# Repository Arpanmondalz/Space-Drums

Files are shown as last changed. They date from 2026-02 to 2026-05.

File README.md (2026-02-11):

# Space Drums

Space Drums is an open source computer vision-based air drumming system. It utilizes a smartphone as a wireless camera to track hand positions via MediaPipe and ESP32-based drumsticks to trigger hits via UDP.

This project enables a virtual drum kit experience in mid-air with real-time audio feedback.

---

## Project Structure

The repository is organized into three primary components:

*   **linux-server/**: The optimized Python server for Linux systems. Recommended for lowest latency.
*   **windows-server/**: The standard Python server for Windows 10 and 11.
*   **firmware/**: C++ firmware for the ESP32-based drumsticks.

---

## Hardware Requirements

*   **Computer**: A laptop or desktop running Linux (Ubuntu/Mint) or Windows 10/11.
*   **Smartphone**: Any modern smartphone with a camera and web browser (used as the video source).
*   **Space Drum sticks**
*   **Network**: Both the computer and smartphone must be connected to the same WiFi network.

---

## Version Comparison

### Linux Version (Recommended)
Optimized for high performance. It utilizes direct kernel access for video (V4L2) and audio (ALSA), achieving sub-10ms audio response and superior frame rate stability. It supports high-priority process scheduling.

### Windows Version
Easier to set up using standard Windows drivers (DirectShow). While latency is slightly higher due to the Windows audio stack, it is fully functional for standard use.

---

## Installation and Setup

### 1. ESP32 Firmware
Flash the code located in the `firmware/` folder to your ESP32 boards.

1.  Open the project in the Arduino IDE or PlatformIO.
2.  Update the WiFi credentials (`SSID` and `PASSWORD`) in the source code.
3.  Flash one stick configured as **LEFT** and the other as **RIGHT** (refer to the definitions at the top of the firmware file).

### 2. Python Server Setup
Ensure Python 3.10 or newer is installed.

#### Linux Setup
Navigate to the `linux-server/` directory and run:
```bash
sudo apt-get install libgl1 libasound2-dev
python3 -m venv venv
source venv/bin/activate
pip install -r requirements.txt
```
*Note: Granting high-priority permissions to the Python executable is recommended for optimal performance.*

#### Windows Setup
Navigate to the `windows-server/` directory in PowerShell:
```powershell
python -m venv venv
.\venv\Scripts\Activate
pip install -r requirements.txt
```

### 3. Audio Files

All audio files can be downloaded from the sounds/ folder

---

## Running the System

1.  **Start the Server:**
    *   **Linux:** `venv/bin/python main.py`
    *   **Windows:** `python main.py`

2.  **Connect the Camera:**
    *   The terminal will display a local IP address (e.g., `http://192.168.1.15:5000`).
    *   Open this address in your smartphone's web browser.
    *   Select **Connect** and grant camera permissions.
    *   Position the phone camera to capture your movements.

3.  **Power on the Sticks:**
    *   Turn on the ESP32 drumsticks.
    *   Only the first time: You will need to connect to the "AirDrums-Stick" wifi network and add your wifi SSID and password for each stick
    *   They will automatically discover the server over UDP.
    *   A confirmation sound will play once both sticks are synchronized.

---

## Troubleshooting

*   **Firewall:** Ensure the computer allows incoming connections on **TCP port 5000** (Video) and **UDP port 5556** (Drum Hits).
*   **Audio Latency:**
    *   **Linux:** Ensure you are using the ALSA configuration provided in the code.
    *   **Windows:** If jitter occurs, set the Python process priority to "Realtime" in the Task Manager.

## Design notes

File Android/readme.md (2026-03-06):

# SpaceDrums android app

## Features

* **Real-Time Pose Tracking:** Uses Google's MediaPipe and Android CameraX to track the user's shoulders, elbows, and wrists at 60 FPS.
* **Hardware IMU Synchronization:** Listens on UDP port `5556` for instant physical strike data from custom hardware sticks, effectively bypassing visual processing delays.
* **Dynamic Drum Zones:** The virtual drum kit (Hi-Hat, Snare, Floor Tom, Crash, Ride) anchors dynamically to the user's body position in the camera feed.
* **Low-Light Detection:** Automatically monitors camera frame gaps and alerts the user if the environment is too dim for accurate 60 FPS tracking.
* **In-App Audio Mixer:** Real-time volume control for individual drum samples using Android's `SoundPool`.

---

## The Physics Engine

The hardest problem in mixed reality is **pipeline latency**. When a physical drumstick hits the "air," the hardware IMU fires instantly over Wi-Fi. However, the camera and neural network pipeline (MediaPipe) run 50–150ms behind physical reality. 

If the app just checked the camera when the IMU fired, the sticks would visually appear mid-air, leading to inaccurate "ghost hits" on the wrong drums. 

### The Solution: Instantaneous Velocity Prediction
SpaceDrums uses a custom `DrumLogic` spatial-temporal engine to solve this entirely in software:

1. **The Flight Recorder:** The camera thread continuously logs the user's arm trajectory and timestamps it using the hardware clock (`SystemClock.uptimeMillis()`).
2. **Terminal Velocity:** When the UDP hit arrives, the engine grabs the last 50ms of visual data to calculate the exact terminal velocity and trajectory of the stick.
3. **Latency Extrapolation:** It calculates the exact millisecond delta between the IMU hardware and the camera pipeline.
4. **The Strike:** It pushes the stick's trajectory forward in time by the calculated latency (e.g., +80ms), predicting exactly where the stick *physically* landed, even if the camera hasn't seen it yet.
5. **Axis-Independent Dampening:** To prevent the stick's natural upward "rebound" from accidentally triggering cymbals, the vertical (Y) extrapolation is heavily dampened while the horizontal (X) movement remains 100% responsive for fast cross-kit fills.

---

## Tech Stack

* **Language:** Kotlin
* **UI Framework:** Jetpack Compose
* **Computer Vision:** MediaPipe Pose Landmarker (Tasks Vision)
* **Camera:** AndroidX Camera2Interop (Forced 60 FPS via hardware requests)
* **Networking:** Java `DatagramSocket` (UDP Multicast & Broadcast)
* **Audio:** Android `SoundPool`

---

## Setup & Requirements

### Software
1. Open the project in **Android Studio**.
2. Sync Gradle dependencies (ensure MediaPipe and CameraX are fetched).
3. Run on a physical Android device (Emulators cannot handle the required camera framerates or UDP network syncing reliably).

### Hardware Context
*This application is designed to pair with external IMU-based hardware.*
* The app acts as the **Server**.
* It expects UDP packets formatted as string commands (`"LEFT"`, `"RIGHT"`, `"KICK"`) broadcasted over the local Wi-Fi network to port `5556`.
* Discovery broadcasts are sent aggressively on port `5555` to help the hardware find the phone's IP address.

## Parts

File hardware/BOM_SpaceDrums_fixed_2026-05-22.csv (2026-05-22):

Reference | Qty | Value | DNP | Exclude from BOM | Exclude from Board | Footprint | Datasheet
A? | 1 | A
C1,C2,C7,C10 | 4 | 4.7µF
C3 | 1 | 22µF
C4,C12,C14 | 3 | 10µF
C5,C8 | 2 | 1µF
C6,C9,C11,C13,C15 | 5 | 0.1µF
H1,H2 | 2 | A2541WR-2P
J1 | 1 | A2541WR-6P
LED1 | 1 | LED0805
LED2 | 1 | MHL3014UBTD
Q1,Q2 | 2 | MMBT3904Q
R1,R4 | 2 | 1kΩ
R2 | 1 | 2kΩ
R3,R5 | 2 | 5.1kΩ
R6 | 1 | 22kΩ
R7 | 1 | 47kΩ
R8,R9,R10,R12 | 4 | 10kΩ
R11,R13 | 2 | 4.7kΩ
R14 | 1 | 470Ω
SW1,SW2 | 2 | TS-1109S-C-E
U1 | 1 | MCP73831T-2ACI/OT
U2 | 1 | CP2102N-A02-GQFN24
U3 | 1 | AP2112K-3.3TRG1
U4 | 1 | LSM6DS3TR-C
U5 | 1 | ESP32-S3-MINI-1-N8
USB1 | 1 | USB4085-GF-A

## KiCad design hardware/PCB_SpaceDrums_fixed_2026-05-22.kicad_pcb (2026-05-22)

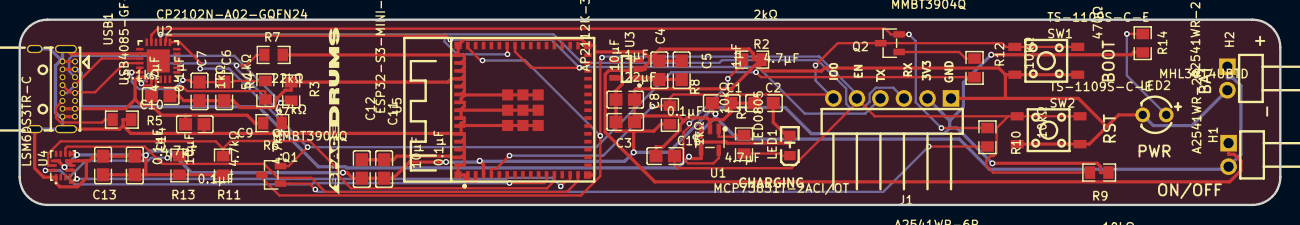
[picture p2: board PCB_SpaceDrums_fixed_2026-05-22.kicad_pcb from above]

Board: 2 copper layers, 136.1 x 20.0 mm, 44 parts (0 on the bottom side), 28 nets.

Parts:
C1, C2, C7, C10: 4.7µF; C0805
C3: 22µF; C0805
C4, C12, C14: 10µF; C0805
C5, C8: 1µF; C0805
C6, C9, C11, C13, C15: 0.1µF; C0805
H1, H2: A2541WR-2P; HDR-TH_2P-P2.54-H-M-W10.0
J1: A2541WR-6P; HDR-TH_6P-P2.54-H-M-W10.3
LED1: LED0805; LED0805-RD
LED2: MHL3014UBTD; LED-TH_BD3.9-P2.54-RD
Q1, Q2: MMBT3904Q; SOT-23-3_L2.9-W1.3-P1.90-LS2.4-BR
R1, R4: 1kΩ; R0805
R2: 2kΩ; R0805
R3, R5: 5.1kΩ; R0805
R6: 22kΩ; R0805
R7: 47kΩ; R0805
R8, R9, R10, R12: 10kΩ; R0805
R11, R13: 4.7kΩ; R0805
R14: 470Ω; R0805
SW1, SW2: TS-1109S-C-E; SW-SMD_4P-L4.5-W4.5-P3.00-LS7.0
U1: MCP73831T-2ACI/OT; SOT-23-5_L3.0-W1.7-P0.95-LS2.8-BL
U2: CP2102N-A02-GQFN24; QFN-24_L4.0-W4.0-P0.50-TL-EP2.5
U3: AP2112K-3.3TRG1; SOT-25-5_L2.9-W1.6-P0.95-LS2.8-BL
U4: LSM6DS3TR-C; LGA-14_L3.0-W2.5-P0.50-TL
U5: ESP32-S3-MINI-1-N8; BULETM-SMD_ESP32-S3-MINI-1-N8
USB1: USB4085-GF-A; USC-C-SMD_USB4085-GF-A

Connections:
3V3: C3.1, C8.1, C11.2, C12.2, C13.2, C14.2, J1.2, R8.2, R9.1, R11.2, R13.2, R14.1, U3.5, U4.5, U4.8, U4.12, U5.3
BAT+: C1.2, H1.2, H2.1, U1.3
CP_8: R6.2, R7.2, U2.8
CP_RX: J1.4, U2.20, U5.39
CP_TX: J1.3, U2.21, U5.40
D+: U2.3, USB1.A6, USB1.B6
D-: U2.4, USB1.A7, USB1.B7
DTR: Q2.2, R10.1, U2.23
EN: C15.2, J1.5, Q1.3, R9.2, SW2.1, SW2.2, U5.45
GND: C1.1, C2.1, C3.2, C4.2, C5.1, C6.1, C7.1, C8.2, C9.1, C10.1, C11.1, C12.1, C13.1, C14.1, C15.1, H2.2, J1.1, LED2.1, R2.2, R3.2, R5.2, R7.1, SW1.3, SW1.4, SW2.3, SW2.4, U1.2, U2.2, U2.25, U3.2, U4.1, U4.6, U4.7, U5.1, U5.2, U5.46, U5.47, U5.48, U5.49, U5.50, U5.51, U5.52, U5.53, U5.54, U5.55, U5.56, U5.57, U5.58, U5.59, U5.60, U5.GND, USB1.A1, USB1.A12, USB1.B1, USB1.B12, USB1.S1
INT1: U4.4, U5.14
INT2: U4.9, U5.15
IO0: J1.6, Q2.3, R8.1, SW1.1, SW1.2, U5.4
LED2_2: LED2.2, R14.2
Q1_1: Q1.1, R10.2
Q2_1: Q2.1, R12.1
R1_1: LED1.1, R1.1
RTS: Q1.2, R12.2, U2.19
SCL: R11.1, U4.13, U5.12
SDA: R13.1, U4.14, U5.11
U1_1: R1.2, U1.1
U1_5: R2.1, U1.5
U2_5: C6.2, C7.2, R4.2, U2.5, U2.6
U2_9: R4.1, U2.9
USB1_A5: R3.1, USB1.A5
USB1_B5: R5.1, USB1.B5
VBUS: C2.2, C9.2, C10.2, LED1.2, R6.1, U1.4, U2.7, USB1.A4, USB1.A9, USB1.B4, USB1.B9
V_SYS: C4.1, C5.2, H1.1, U3.1, U3.3

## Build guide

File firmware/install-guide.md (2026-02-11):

# ESP32-S3 Firmware Upload Guide

This guide provides the necessary steps to configure the Arduino IDE and upload firmware to an ESP32-S3 Dev Module.

---

## Prerequisites

*   **Arduino IDE:** Ensure you have the latest version installed.
*   **ESP32 Board Package:** 
    1.  In Arduino IDE, go to **File > Preferences**.
    2.  In "Additional Boards Manager URLs", paste: `https://raw.githubusercontent.com/espressif/arduino-esp32/gh-pages/package_esp32_index.json`
    3.  Go to **Tools > Board > Boards Manager**, search for "esp32" by Espressif Systems, and click install.

---

## Phase 1: Arduino IDE Configuration

To ensure the ESP32-S3 functions correctly, you must select the specific board and hardware settings. Navigate to the **Tools** menu and set the following:

*   **Board:** "ESP32S3 Dev Module"
*   **USB CDC On Boot:** Disabled
*   **Flash Mode:** QIO 80MHz
*   **Flash Size:** 8MB (Or match your specific module's capacity)
*   **Core Debug Level:** None

**NOTE:** You will need to update STICK_ID to "Right" or "Left" based on which stick you are uploading the code to. 

---

## Phase 2: Connecting the Hardware

1.  Connect your ESP32-S3 to your computer using a high-quality USB data cable.
2.  Go to **Tools > Port** and select the COM port associated with your device (e.g., COM3 or COM5).

---

## Phase 3: Entering Bootloader Mode

If the Arduino IDE fails to connect to the board automatically, you must manually put the ESP32-S3 into "Download Mode" using the physical buttons on the module.

Follow this exact sequence:

1.  **Press and hold** the **BOOT** button.
2.  While still holding BOOT, **press** the **RESET** (or EN) button.
3.  **Release** the **RESET** button.
4.  **Release** the **BOOT** button.

The board is now in firmware upload mode. 

---

## Phase 4: Uploading the Code

1.  In the Arduino IDE, click the **Upload** icon (the right-pointing arrow) or press `Ctrl + U`.
2.  Wait for the console at the bottom to show "Writing at 0x00001000..." and eventually **"Leaving... Hard resetting via RTS pin..."**
3.  Once the upload is complete, you may need to press the **RESET** button once more to start the program.

---

**NOTE:** You will need to connect to the "AirDrums-Stick" wifi network and add your wifi SSID and password for each stick when you boot them up the first time

## Troubleshooting

*   **Port not visible:** Ensure you are using a data cable and not a charge-only cable. Try a different USB port or reinstall the CP210x or CH340 drivers if required.
*   **Upload Failed:** Ensure you followed the button sequence in Phase 3 correctly. The timing of releasing the Reset button while holding Boot is critical.
*   **Serial Monitor Blank:** Ensure the Baud Rate in the Serial Monitor matches the `Serial.begin()` value in your code (usually 115200).

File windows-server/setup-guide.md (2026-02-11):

# Space Drums: Windows Setup Guide

This guide details the procedure for setting up the Air Drums server on Windows 10 or 11.

---

## Prerequisites

*   **Operating System:** Windows 10 or 11.
*   **Python:** Version 3.10, 3.11, or 3.12 installed.
    *   **Important:** During installation, ensure the box **"Add Python to PATH"** is checked.
*   **Hardware:** Webcam or smartphone, and ESP32 Drumsticks.

---

## Phase 1: Project Setup

Follow these steps using PowerShell to initialize the project directory and virtual environment.

1.  **Create the directory structure:**
    ```powershell
    New-Item -ItemType Directory -Force -Path "$HOME\Documents\airdrums"
    cd "$HOME\Documents\airdrums"
    New-Item -ItemType Directory -Force -Path "sounds"
    ```

2.  **Create the Virtual Environment:**
    ```powershell
    python -m venv venv
    ```

3.  **Activate the Environment:**
    If you receive a security error, run: `Set-ExecutionPolicy RemoteSigned -Scope CurrentUser` first.
    ```powershell
    .\venv\Scripts\Activate
    ```
    Once activated, your command prompt will be prefixed with `(venv)`.

---

## Phase 2: Install Libraries

Run the following command to install the required dependencies:

```bash
pip install opencv-python mediapipe pygame flask flask-socketio eventlet numpy
```

---

## Phase 3: Network and Firewall Configuration

The Windows Defender Firewall frequently blocks the server's network communication.

### Handling the Firewall Prompt
When you run the script for the first time, a Windows Defender Firewall dialog will appear.
1.  **Check both boxes:**
    *   Private networks (home or work)
    *   Public networks (airport, coffee shop)
2.  **Select:** Allow Access.

### Manual Configuration
If you did not see the popup or the connection is blocked:
1.  Search the Start Menu for **"Allow an app through Windows Firewall"**.
2.  Click **Change settings**.
3.  Locate `python.exe` in the list.
4.  Ensure both **Private** and **Public** checkboxes are selected for all Python entries.

---

## Phase 4: Finding your IP Address

To connect your phone to the server, you must identify your computer's local IP address.

1.  Open PowerShell.
2.  Type the following command:
    ```powershell
    ipconfig
    ```
3.  Locate the **IPv4 Address** under your active network adapter (typically *Wireless LAN adapter Wi-Fi*).
    *   Example: `192.168.1.15`
4.  Enter the address into your phone's browser using port 5000:
    `http://192.168.1.15:5000`

---

## Troubleshooting

### Error: ImportError: DLL load failed (OpenCV)
*   **Cause:** Missing Windows Media Feature Pack, common on Windows "N" editions.
*   **Fix:** Navigate to `Windows Settings > Apps > Optional Features` and install the **Media Feature Pack**.

### Error: Audio Crackling
*   **Cause:** The audio buffer size is too low for standard Windows drivers.
*   **Fix:** Modify the buffer setting in your Python script from `64` to `512`.
    ```python
    pygame.mixer.pre_init(frequency=44100, size=-16, channels=2, buffer=512)
    ```

### Error: Phone connects but the screen remains black
*   **Cause:** The firewall is blocking the video stream on port 5000.
*   **Fix:** Temporarily disable the Windows Firewall to confirm the cause. If the stream works, re-configure the firewall rules as detailed in Phase 3.

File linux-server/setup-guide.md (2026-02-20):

# Space Drums: Linux Setup Guide

This guide details the setup for the Air Drums server on Linux:

- **Ubuntu 24.04+, Linux Mint 22+, Debian-based**
- **Fedora 39+, RHEL-based**

This version is optimized for **sub-5ms latency** using direct ALSA audio and real-time process scheduling.

---

## Prerequisites

- **OS:** Ubuntu 24.04+, Mint 22+, Fedora 39+, or newer
- **Hardware:** Webcam or smartphone, ESP32 Drumsticks
- **Network:** Computer and smartphone must be on the same WiFi network

---

## Phase 1: System Dependencies

Install required system libraries for audio (ALSA), graphics (OpenGL), and Python virtual environments.

### Debian / Ubuntu / Mint (APT)

```bash
sudo apt update
sudo apt install python3-venv python3-pip libgl1 libglib2.0-0t64 libasound2-dev libcap2-bin
```

### Fedora / RHEL (DNF)

```bash
sudo dnf install python3 python3-pip mesa-libGL glib2 alsa-lib-devel libcap
```

**Fedora Notes:**

| Debian/Ubuntu Name | Fedora Equivalent | Notes |
|---|---|---|
| `python3-venv` | `python3` | venv is included by default |
| `libgl1` | `mesa-libGL` | OpenGL rendering |
| `libglib2.0-0t64` | `glib2` | GLib library |
| `libasound2-dev` | `alsa-lib-devel` | ALSA audio headers |
| `libcap2-bin` | `libcap` | Provides `setcap` |

To verify venv works on Fedora:

```bash
python3 -m venv --help
```

---

## Phase 2: Virtual Environment Setup

To prevent dependency conflicts, install MediaPipe before other libraries.

```bash
# 1. Create project directory
mkdir -p ~/airdrums/sounds
cd ~/airdrums

# 2. Setup environment
python3 -m venv venv
source venv/bin/activate

# 3. Install core dependencies
pip install --upgrade pip setuptools wheel
pip install mediapipe==0.10.14
pip install opencv-python pygame flask flask-socketio eventlet numpy
```

---

## Phase 3: High-Performance Configuration

To achieve low latency, you must grant the Python executable permission to use real-time scheduling ("Nice" values) without running as root. **Do not run the server with sudo**, as it will break the audio connection.

Run this command to grant the necessary permissions:

```bash
sudo setcap 'cap_sys_nice=eip' $(readlink -f venv/bin/python)
```

If `setcap` is not found on Fedora:

```bash
sudo dnf install libcap
```

---

## Phase 4: Firewall and Audio Files

### 1. Open Required Ports

**Debian / Ubuntu / Mint (UFW):**

```bash
sudo ufw allow 5000/tcp   # Smartphone Video Stream
sudo ufw allow 5556/udp   # ESP32 Drum Hits
```

**Fedora / RHEL (firewalld):**

```bash
sudo firewall-cmd --permanent --add-port=5000/tcp
sudo firewall-cmd --permanent --add-port=5556/udp
sudo firewall-cmd --reload
```

### 2. Add Sound Files

Place your `.wav` files (snare, hihat, tom, crash) into the `~/airdrums/sounds/` directory.

---

## Phase 5: Running the System

1. **Navigate to the folder:**
    ```bash
    cd ~/airdrums
    ```

2. **Activate the environment (if not already active):**
    ```bash
    source venv/bin/activate
    ```

3. **Start the server:**
    ```bash
    python drums.py
    ```

4. **Verify Status:**
    The terminal should display: `[LINUX] High Priority Mode: ACTIVE`.

---

## Troubleshooting

- **Audio Error (Host is down):** This usually happens if you ran the script with `sudo`. Run the `setcap` command in Phase 3 and launch as a standard user.

- **ModuleNotFoundError (Mediapipe):** If MediaPipe fails to load, delete the `venv` folder and reinstall, ensuring MediaPipe is installed first.

- **Video Lag:** If the laptop camera struggles, edit the script to lower the `CAP_PROP_FPS` from 60 to 30.

- **Permissions:** If high priority is not active, ensure the `setcap` command was pointed at the correct Python binary inside your virtual environment:
    ```bash
    readlink -f venv/bin/python
    ```
    Re-run the `setcap` command if necessary.

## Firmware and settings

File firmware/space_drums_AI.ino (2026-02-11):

/*
 * Space Drums - ESP32-S3 Firmware
 * Compatible with Python "Master Server"
 * * INSTRUCTIONS:
 * 1. Flash this to your LEFT stick first.
 * 2. Change STICK_ID to "RIGHT" and flash your second stick.
 */

#include <WiFi.h>
#include <WiFiManager.h>
#include <WiFiUdp.h>
#include <Adafruit_LSM6DS3TRC.h>
#include <Wire.h>

// ==================== STICK IDENTITY ====================
#define STICK_ID "Right"  // Options: "LEFT" or "RIGHT"

// ==================== PIN CONFIGURATION ====================
const int PIN_SDA  = 7;
const int PIN_SCL  = 8;
const int PIN_INT1 = 10;

// ==================== NETWORK CONFIGURATION ====================
const uint16_t UDP_DISCOVERY_PORT = 5555; // Listening for Server Broadcast
const uint16_t UDP_HIT_PORT       = 5556; // Sending Hits to Server

// ==================== HIT DETECTION TUNING ====================
// (Your tuned values - DO NOT TOUCH)
const float    MIN_DOWN_VELOCITY  = -0.6f;
const float    IMPACT_ACCEL_MS2   = -14.0f;
const uint32_t HIT_COOLDOWN_MS    = 80;
const float    VELOCITY_DECAY     = 0.94f;
const float    GRAVITY_MS2        = 9.81f;

// ==================== CALIBRATION ====================
const uint32_t CALIBRATION_DELAY_MS = 500;
const uint32_t CALIBRATION_TIME_MS  = 2000;

// ==================== OBJECTS ====================
Adafruit_LSM6DS3TRC imu;
WiFiUDP udpRx; // For receiving broadcast
WiFiUDP udpTx; // For sending hits

// ==================== STATE ====================
volatile bool isCalibrated = false;
float gravityZ_g = 1.0f;

float velocityZ = 0.0f;
unsigned long lastSampleMicros = 0;
unsigned long lastHitMs = 0;

IPAddress serverIP;
volatile bool serverFound = false;
unsigned long lastServerSeen = 0;

QueueHandle_t hitQueue;

// ==================== CALIBRATION ROUTINE ====================
void calibrateGravity() {
    Serial.println("\n[CAL] Hold still...");
    delay(CALIBRATION_DELAY_MS);

    float sumZ = 0.0f;
    int samples = 0;
    unsigned long start = millis();
    sensors_event_t accel, gyro, temp;

    while (millis() - start < CALIBRATION_TIME_MS) {
        if (imu.getEvent(&accel, &gyro, &temp)) {
            sumZ += accel.acceleration.z;
            samples++;
        }
        delayMicroseconds(500);
    }

    if (samples > 100) {
        gravityZ_g = (sumZ / samples) / GRAVITY_MS2;
        gravityZ_g = constrain(gravityZ_g, -1.1f, 1.1f);
        isCalibrated = true;
        Serial.printf("[CAL] Gravity Z = %.3f g (%d samples)\n", gravityZ_g, samples);
    } else {
        Serial.println("[CAL] Failed, using default gravity");
        gravityZ_g = 1.0f;
        isCalibrated = true;
    }
}

// ==================== SENSOR TASK ====================
void imuTask(void* param) {
    sensors_event_t accel, gyro, temp;
    while (!isCalibrated) vTaskDelay(10);

    lastSampleMicros = micros();

    while (true) {
        if (imu.getEvent(&accel, &gyro, &temp)) {
            unsigned long now = micros();
            float dt = (now - lastSampleMicros) * 1e-6f;
            lastSampleMicros = now;
            
            // Filter crazy time jumps
            if (dt <= 0 || dt > 0.05f) continue;

            // Remove Gravity
            float accelZ_g = accel.acceleration.z / GRAVITY_MS2;
            float accelZ_linear_g = accelZ_g - gravityZ_g;
            float accelZ_ms2 = accelZ_linear_g * GRAVITY_MS2;

            // Velocity Integration
            velocityZ += accelZ_ms2 * dt;
            velocityZ *= VELOCITY_DECAY;

            // Hit Logic
            unsigned long nowMs = millis();
            bool strongImpact = accelZ_ms2 < IMPACT_ACCEL_MS2;
            bool movingDownFast = velocityZ < MIN_DOWN_VELOCITY;
            bool notSwingUp = accelZ_ms2 < 0.0f;   
            bool cooldownOK = (nowMs - lastHitMs) > HIT_COOLDOWN_MS;

            if (strongImpact && movingDownFast && notSwingUp && cooldownOK) {
                lastHitMs = nowMs;
                velocityZ = 0.0f;
                
                // Signal the Network Task
                uint8_t hit = 1;
                xQueueSend(hitQueue, &hit, 0);
                
                // Debug Print
                Serial.printf(">>> HIT (%s) <<<\n", STICK_ID);
            }
        }
        vTaskDelay(1); // Yield to prevent watchdog crash
    }
}

// ==================== NETWORK TASK ====================
void networkTask(void* param) {
    udpRx.begin(UDP_DISCOVERY_PORT);
    udpTx.begin(UDP_HIT_PORT);

    Serial.printf("[NET] Listening for Python Server on Port %d...\n", UDP_DISCOVERY_PORT);
    char rxBuf[64];

    while (true) {
        // 1. LISTEN FOR SERVER BROADCAST
        int size = udpRx.parsePacket();
        if (size > 0) {
            int len = udpRx.read(rxBuf, sizeof(rxBuf) - 1);
            if (len > 0) {
                rxBuf[len] = '\0';
                // Check if the packet is from our Python script
                if (strncmp(rxBuf, "AIRDRUM_SERVER", 14) == 0) {
                    serverIP = udpRx.remoteIP();
                    if (!serverFound) {
                        Serial.printf("[NET] FOUND SERVER AT: %s\n", serverIP.toString().c_str());
                    }
                    serverFound = true;
                    lastServerSeen = millis();
                }
            }
        }

        // 2. CHECK CONNECTION HEALTH
        if (serverFound && millis() - lastServerSeen > 5000) {
            serverFound = false;
            Serial.println("[NET] Lost connection to server");
        }

        // 3. SEND HITS FROM QUEUE
        uint8_t hit;
        while (xQueueReceive(hitQueue, &hit, 0) == pdTRUE) {
            if (serverFound) {
                udpTx.beginPacket(serverIP, UDP_HIT_PORT);
                
                // --- THE CRITICAL UPDATE ---
                // Sends "HIT:LEFT" or "HIT:RIGHT"
                udpTx.print("HIT:");
                udpTx.print(STICK_ID); 
                
                udpTx.endPacket();
            } else {
                Serial.println("[NET] Hit ignored - No Server Found");
            }
        }
        vTaskDelay(1);
    }
}

// ==================== SETUP ====================
void setup() {
    Serial.begin(115200);
    delay(1000);

    // I2C Init
    Wire.begin(PIN_SDA, PIN_SCL);
    Wire.setClock(400000);

    // IMU Init
    if (!imu.begin_I2C()) {
        Serial.println("[IMU] HARDWARE ERROR - CHECK WIRING");
        while (1) delay(1000);
    }
    
    // IMU Settings (High Speed)
    imu.setAccelRange(LSM6DS_ACCEL_RANGE_8_G);
    imu.setAccelDataRate(LSM6DS_RATE_833_HZ);
    imu.setGyroRange(LSM6DS_GYRO_RANGE_1000_DPS);
    imu.setGyroDataRate(LSM6DS_RATE_833_HZ);

    // WiFi Init (Auto-Connect Portal)
    WiFiManager wm;
    // wm.resetSettings(); // Uncomment if you need to reset WiFi credentials
    if (!wm.autoConnect("AirDrums-Stick", "airdrums123")) {
        ESP.restart();
    }

    // Task & Queue Init
    hitQueue = xQueueCreate(16, sizeof(uint8_t));
    calibrateGravity(); // Get initial orientation

    // Multithreading: 
    // Core 1 = Sensor Fusion (Fast)
    // Core 0 = WiFi/Network (Slow)
    xTaskCreatePinnedToCore(imuTask, "IMU", 4096, NULL, 2, NULL, 1);
    xTaskCreatePinnedToCore(networkTask, "NET", 4096, NULL, 1, NULL, 0);

    Serial.printf("[SYSTEM] %s Stick Ready!\n", STICK_ID);
}

void loop() {
    vTaskDelay(pdMS_TO_TICKS(1000)); // Nothing to do here
}

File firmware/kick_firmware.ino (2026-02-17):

/*
 * Space Drums - KICK MODULE (Foot)
 * Hardware: ESP32-S3 + LSM6DS3TR-C
 * Mounting: Securely to the top of the shoe (laces)
 */

#include <WiFi.h>
#include <WiFiManager.h>
#include <WiFiUdp.h>
#include <Adafruit_LSM6DS3TRC.h>
#include <Wire.h>

// ==================== IDENTITY ====================
#define STICK_ID "KICK" 

// ==================== PIN CONFIGURATION ====================
const int PIN_SDA  = 7;
const int PIN_SCL  = 8;

// ==================== NETWORK CONFIGURATION ====================
const uint16_t UDP_DISCOVERY_PORT = 5555; 
const uint16_t UDP_HIT_PORT       = 5556; 

// ==================== KICK TUNING ====================
// The threshold for a "Stomp". 
// Gravity is ~9.8m/s^2. A stomp usually exceeds 20-30m/s^2.
// We look for a sudden DELTA (change) in acceleration.
const float    STOMP_THRESHOLD_G  = 1.8f;  // Sensitivity (Lower = easier to trigger)
const uint32_t HIT_COOLDOWN_MS    = 90;    // Prevent double-triggering on one stomp

// ==================== OBJECTS ====================
Adafruit_LSM6DS3TRC imu;
WiFiUDP udpRx;
WiFiUDP udpTx;

// ==================== STATE ====================
IPAddress serverIP;
volatile bool serverFound = false;
unsigned long lastServerSeen = 0;

QueueHandle_t hitQueue;

// ==================== SENSOR TASK (CORE 1) ====================
void imuTask(void* param) {
    sensors_event_t accel, gyro, temp;
    float lastAccelZ = 0;
    unsigned long lastHitTime = 0;

    // Initialize initial reading
    if(imu.getEvent(&accel, &gyro, &temp)) {
        lastAccelZ = accel.acceleration.z;
    }

    while (true) {
        if (imu.getEvent(&accel, &gyro, &temp)) {
            float currentZ = accel.acceleration.z / 9.81f; // Convert to Gs
            
            // Calculate the "Shock" (High Pass Filter)
            // This ignores gravity and only sees sudden changes
            float shock = abs(currentZ - lastAccelZ);
            lastAccelZ = currentZ;

            unsigned long now = millis();

            // HIT DETECTION LOGIC
            // 1. Shock must be strong enough
            // 2. Must be outside the cooldown window
            if (shock > STOMP_THRESHOLD_G && (now - lastHitTime > HIT_COOLDOWN_MS)) {
                
                // Register Hit
                lastHitTime = now;
                uint8_t hit = 1;
                xQueueSend(hitQueue, &hit, 0);
                
                Serial.printf(">>> KICK (Shock: %.2fg) <<<\n", shock);
            }
        }
        // Run slightly slower than sticks, precise integration isn't needed for kicks
        vTaskDelay(2); 
    }
}

// ==================== NETWORK TASK (CORE 0) ====================
void networkTask(void* param) {
    udpRx.begin(UDP_DISCOVERY_PORT);
    udpTx.begin(UDP_HIT_PORT);

    Serial.printf("[NET] Listening for Python Server...\n");
    char rxBuf[64];

    while (true) {
        // 1. Discovery
        int size = udpRx.parsePacket();
        if (size > 0) {
            int len = udpRx.read(rxBuf, sizeof(rxBuf) - 1);
            if (len > 0) {
                rxBuf[len] = '\0';
                if (strncmp(rxBuf, "AIRDRUM_SERVER", 14) == 0) {
                    serverIP = udpRx.remoteIP();
                    if (!serverFound) Serial.printf("[NET] CONNECTED: %s\n", serverIP.toString().c_str());
                    serverFound = true;
                    lastServerSeen = millis();
                }
            }
        }

        // 2. Watchdog
        if (serverFound && millis() - lastServerSeen > 5000) {
            serverFound = false;
            Serial.println("[NET] Lost connection...");
        }

        // 3. Send Hits
        uint8_t hit;
        while (xQueueReceive(hitQueue, &hit, 0) == pdTRUE) {
            if (serverFound) {
                udpTx.beginPacket(serverIP, UDP_HIT_PORT);
                udpTx.print("HIT:");
                udpTx.print(STICK_ID); 
                udpTx.endPacket();
            }
        }
        vTaskDelay(1);
    }
}

// ==================== SETUP ====================
void setup() {
    Serial.begin(115200);
    delay(1000);

    Wire.begin(PIN_SDA, PIN_SCL);
    
    if (!imu.begin_I2C()) {
        Serial.println("IMU NOT FOUND!");
        while (1) delay(100);
    }

    // High Speed Settings
    imu.setAccelRange(LSM6DS_ACCEL_RANGE_8_G); // Higher range for foot impacts
    imu.setAccelDataRate(LSM6DS_RATE_416_HZ);  // Plenty fast for kicks

    WiFiManager wm;
    if (!wm.autoConnect("AirDrums-Kick", "airdrums123")) {
        ESP.restart();
    }

    hitQueue = xQueueCreate(10, sizeof(uint8_t));

    // Launch Tasks
    xTaskCreatePinnedToCore(imuTask, "IMU", 4096, NULL, 2, NULL, 1);
    xTaskCreatePinnedToCore(networkTask, "NET", 4096, NULL, 1, NULL, 0);
}

void loop() {
    vTaskDelay(1000);
}

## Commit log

2026-02-11 Add ESP32-S3 Firmware Upload Guide
    This guide outlines the steps to configure the Arduino IDE and upload firmware to the ESP32-S3 Dev Module, including prerequisites, IDE configuration, hardware connection, bootloader mode entry, code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
2026-02-11 Add connection instructions for ESP32 drumsticks
    Added instructions for connecting to the 'AirDrums-Stick' wifi network and configuring wifi SSID and password.
2026-02-17 Add kick firmware for ESP32-S3 with IMU support
2026-02-20 Implement Kalman filter and headless mode for performance
    Add performance enhancements with Kalman filter and headless mode.
2026-02-20 Added kalman smoothing filter and headless mode
2026-04-06 Added hardware files
    [SCH_spacedrums_Altium.schdoc]
2026-05-22 Added Kicad files and BOM
    [BOM_SpaceDrums_fixed_2026-05-22.csv, PCB_SpaceDrums_fixed_2026-05-22.kicad_pcb, SCH_SpaceDrums_fixed_2026-05-22.kicad_sch]
